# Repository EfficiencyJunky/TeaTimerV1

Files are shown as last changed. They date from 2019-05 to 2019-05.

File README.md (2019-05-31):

# TeaTimer

This is a simple yet elegant tea timer that will allow you to properly time your brews every time! You can build one yourself with the components listed in the BOM, and then upload the Arduino code in the "TeaTimer_Main_V1" folder to make it work. If you have access to a 3D printer, you can print an enclosure using the files in the "3DPrintFiles" folder  to make it easy to assemble and look more polished.

Of course this is all up for interpretation! Please take this project and modify it and make it everything you want it to be. The simplest modification would be simply to purchase a smaller, cheaper battery. You could easily knock $10 off the price, make it smaller, and it will work just as well.

For what it's worth though, I will provide documentation on how I built mine in case you want a good a good place to start.

# See it in action
For some background into why I made this, and a demo of it in action, check out my instagram post here:
[https://www.instagram.com/p/ByHbxj5pm57/](https://www.instagram.com/p/ByHbxj5pm57/)

# Build your own!
This project is a great way to get your feet wet in DIY product making. It requires only basic knowledge of Arduino, breadboarding, soldering, and optional 3D Printing.

### Acquire the Parts
The version I built cost around $60 in parts. All of the components can be purchased on Adafruit.com 

Here's the parts list (aka BOM or Bill of Materials) with links and descriptions of everything you'll need to create your very own Tea Timer V1
[BOM-aka-parts_list.csv](https://github.com/EfficiencyJunky/TeaTimerV1/blob/master/BOM-aka-parts_list.csv "BOM-aka-parts_list.csv")

Once you have the parts, you will need to do a little bit of Soldering to get them all prepped to plug and play.

The hardest soldering job will be soldering the Adafruit LiIon/LiPoly Backpack onto the Pro Trinket. They sort of describe how to do this on the product page, so hopefully it's not too hard to figure that out! Before you solder the Backpack to the Trinket Pro though, be sure to solder a dual header or pair of wires with at least 8 inches to the two holes on the LiIon/LiPoly Backpack that allow you to attach an on/off switch. Here's a picture that shows what I'm talking about
[https://cdn-shop.adafruit.com/970x728/2124-01.jpg](https://cdn-shop.adafruit.com/970x728/2124-01.jpg)
Of course the switch I have spec'd in the BOM is not the same switch in the picture, but the connections will be the same. In my build, I soldered a right angle dual header instead of bare wires and avoided soldering to the on/off switch by using one of these Arcade Button Quick-Connect Pairs (included in the BOM https://www.adafruit.com/product/1152)

Besides that, the only other soldering jobs will be connecting wires to terminals on the On/Off switch, 8 Position Rotary Switch, and Button with RGB LED.

Here's a picture that shows how I connected all the wires:
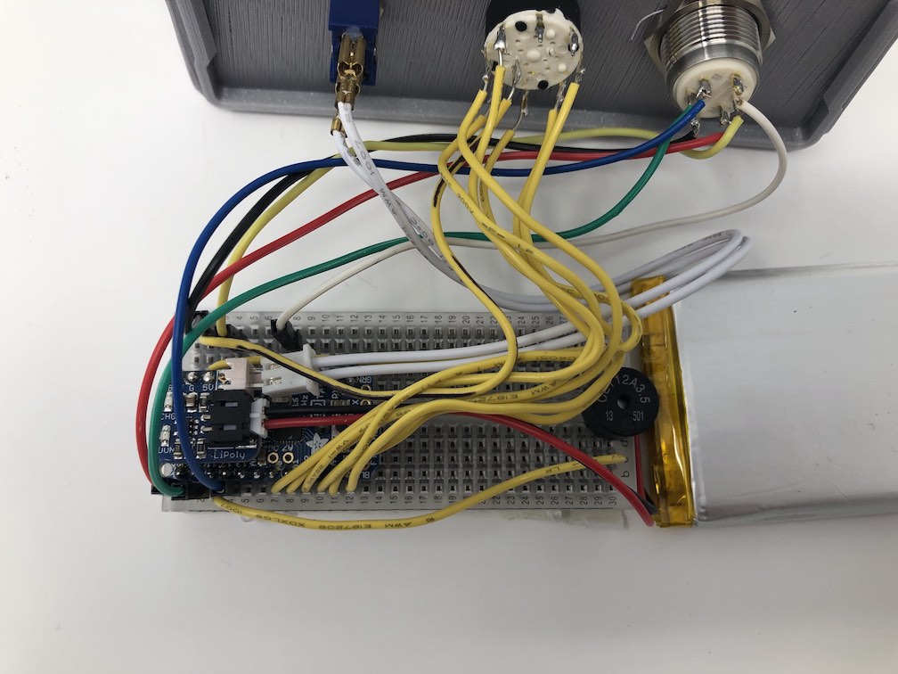
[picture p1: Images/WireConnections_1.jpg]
Wire Connections 1


I know it's probably not the easiest to follow, but it's all I got for now.

I'll be adding an entire schematic to make this all a lot easier as soon as I can.

For now, I need to go to sleep!
<!--stackedit_data:
eyJoaXN0b3J5IjpbLTEwMTE0MTc5NTIsMTAwMjQ2MzI3Myw4Mz
Q3OTA3ODcsMTIzMDY1MzY4MV19
-->

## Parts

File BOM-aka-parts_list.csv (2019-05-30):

Line Number | Manufacturer | Manufacturer P/N | Description | Vendor | Vendor P/N | Quantity | Price/Unit | Total Price | Link | Datasheet/CAD | Notes
01 | Adafruit |  | Pro Trinket - 5V 16MHz | Adafruit | 2000 | 1 | $9.95 | $9.95 | https://www.adafruit.com/product/2000
02 | Adafruit |  | Pro Trinket LiIon/LiPoly Backpack | Adafruit | 2124 | 1 | $4.95 | $4.95 | https://www.adafruit.com/product/2124
03 | Adafruit |  | Lithium Ion Polymer Battery - 3.7v 2500mAh | Adafruit | 328 | 1 | $14.95 | $14.95 | https://www.adafruit.com/product/328
04 | Adafruit |  | Mini Panel Mount SPDT Toggle Switch | Adafruit | 3221 | 1 | $0.95 | $0.95 | https://www.adafruit.com/product/3221
05 | Adafruit |  | Mini 8-Way Rotary Selector Switch - SP8T | Adafruit | 2925 | 1 | $1.95 | $1.95 | https://www.adafruit.com/product/2925
06 | Adafruit |  | Slim Metal Potentiometer Knob - 10mm Diameter x 10mm - T18 | Adafruit | 2058 | 1 | $0.95 | $0.95 | https://www.adafruit.com/product/2058
07 | Adafruit |  | Rugged Metal Pushbutton - 16mm 6V RGB Momentary | Adafruit | 3350 | 1 | $10.95 | $10.95 | https://www.adafruit.com/product/3350
08 | Adafruit |  | Buzzer 5V - Breadboard friendly | Adafruit | 1536 | 1 | $0.95 | $0.95 | https://www.adafruit.com/product/1536 | http://www.chinasound.com/Product/CET/CET12A3.5-42-2.0R.htm
09 | Adafruit |  | Half-size breadboard | Adafruit | 64 | 1 | $5.00 | $5.00 | https://www.adafruit.com/product/64
10 | Adafruit |  | Arcade/Button Quick-Connect Wire Pair - Set of 10 pairs | Adafruit | 1152 | 1 | $4.95 | $4.95 | https://www.adafruit.com/product/1152
11 | Adafruit |  | Solid-Core Wire Spool - 25ft - 22AWG - Yellow | Adafruit | 289 | 1 | $2.95 | $2.95 | https://www.adafruit.com/product/289
12 | Adafruit |  | Premium Male/Male Jumper Wires - 20 x 6" (150mm) | Adafruit | 1957 | 1 | $1.95 | $1.95 | https://www.adafruit.com/product/1957
13 | Local hardware store |  | m3 x 15mm (or 16mm) screw | Hardware store |  | 2 | $0.10 | $0.20
14 | Local hardware store |  | m3 hex nut | Hardware store |  | 2 | $0.10 | $0.20
 |  |  |  |  |  |  | TOTAL | $60.85

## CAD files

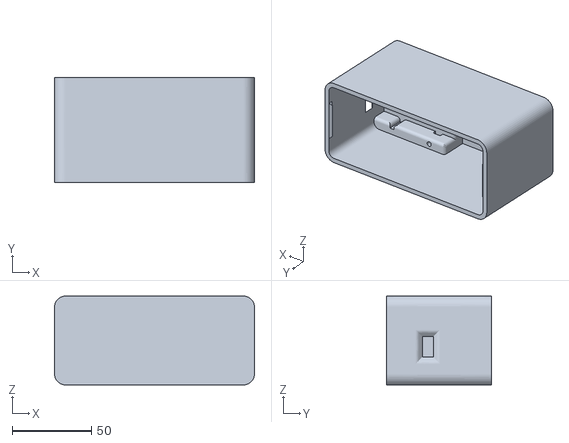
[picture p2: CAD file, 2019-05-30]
3DPrintFiles/Enclosure_Tea Timer Enclosure V1 v17_Case_v2.stl
126.0 x 66.0 x 56.0

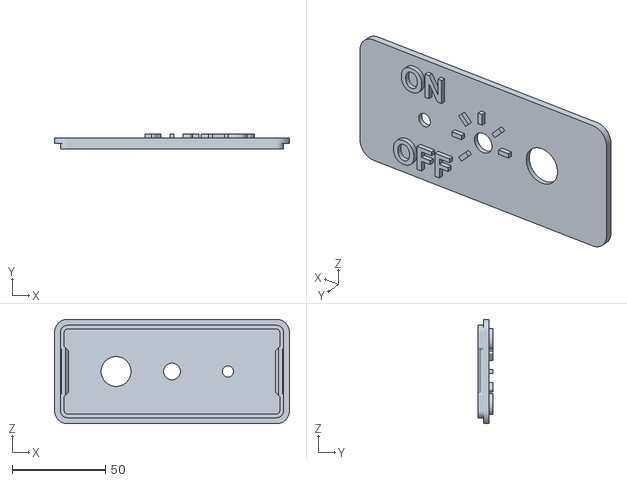
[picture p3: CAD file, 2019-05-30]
3DPrintFiles/Enclosure_Tea Timer Enclosure V1 v11_Top Cover_1_Top Cover_Top Cover.stl
126.0 x 8.00 x 56.0

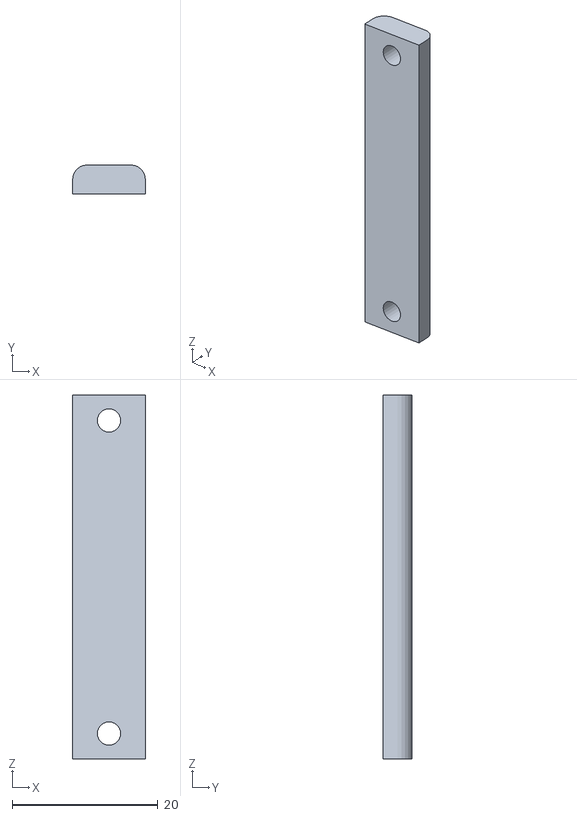
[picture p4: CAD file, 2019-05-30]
3DPrintFiles/Enclosure_Tea Timer Enclosure V1 v11_Case_1_Bridge to secure PCB.stl
10.0 x 4.00 x 50.0

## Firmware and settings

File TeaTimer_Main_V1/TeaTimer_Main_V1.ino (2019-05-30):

/*
  Welcome to the TeaTimer V1 - This is a simple yet elegant code base for creating a tea timer (or any kind of timer) 
                                that doesn't use the dreaded process blocking "delay()" function so that the user is free
                                to push that damn button anytime they please!

                                The timing and speed of everything is set up to work with the Adafruit Trinket Pro 5V
                                If you use a faster Arduino board, you may need to modify the variables
                                "ledFadeInterval" and "LEDFadeIndexStepIncrementAmount" in the MyStateMachine.cpp class

                                Ok enough chit chat, enjoy drinking your perfectly brewed tea!
*/


#include "MyStateMachine.cpp"

#define BUTTON_PIN 5
#define NUM_ROTARY_POSITIONS 6

// migrate this define and enum to the MyStateMachine class
//#define COMMON_ANODE

// Program State types supported:
//enum  states { NONE, COUNTING_DOWN, COUNTDOWN_COMPLETE};
 
int redPin = 9;
int greenPin = 10;
int bluePin = 12;

int buzzerPin = 11;

const int buttonPin = 4;     // the number of the pushbutton pin


int systemState = 0;

int rotaryKnobMinuteSelection = 0;
int rotaryKnobPinCount = 1;

static const uint8_t analog_pins[] = {A0,A1,A2,A3,A4,A5};

// no longer need this class. It was fun while it lasted, but the StateMachine is better
//MyButtonClass TheButton(buttonPin);

MyStateMachine StateMachine(redPin, greenPin, bluePin, buzzerPin);

void setup() {
  // put your setup code here, to run once:
  pinMode(redPin, OUTPUT);
  pinMode(greenPin, OUTPUT);
  pinMode(bluePin, OUTPUT);
  
  pinMode(buttonPin, INPUT_PULLUP);

  pinMode(A0, INPUT_PULLUP);
  pinMode(A1, INPUT_PULLUP);
  pinMode(A2, INPUT_PULLUP);
  pinMode(A3, INPUT_PULLUP);
  pinMode(A4, INPUT_PULLUP);
  pinMode(A5, INPUT_PULLUP);

  //Serial.begin();
  delay(10);
  StateMachine.setColor(0, 0, 255);  // Blue light is initial state
}


// States
// 1) Idle
// 2) Counting down
// 3) Countdown Complete


void loop() {
  // put your main code here, to run repeatedly:
  // TheButton.Update(millis());
  StateMachine.Update(millis());


  if (digitalRead(buttonPin) == LOW) // Button pressed
  {

    //Serial.println("KnobCount: ");
    
      // this sets everything in motion and makes it so that if a person presses the button more than once,
      // it will work no matter what state the StateMachine is in
      StateMachine.StartCountdown(GetNumMinutesForTimer()+1); // add 1 because the index starts at 0
      
  }


}

// a relatively efficient way to read all the pins and find the one that is low (aka the one that the rotary switch is set to)
// we'll use this to set the number of minutes to countdown
unsigned long GetNumMinutesForTimer(){

  unsigned long rotaryKnobPinCount = 0;
  
  while((digitalRead(analog_pins[rotaryKnobPinCount]) != LOW) && (rotaryKnobPinCount < NUM_ROTARY_POSITIONS)){
  
      rotaryKnobPinCount++;
  }

  return rotaryKnobPinCount;

}

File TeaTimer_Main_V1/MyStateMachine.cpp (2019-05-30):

/*
  MyStateMachine.cpp - This is a simple state machine to gracefully handle setting the three states of the tea timer system, as well as 
                          the proper audio/visual feedback in the form of an RGB LED and Piezzo Speaker.
  
                          The 3 states are:
                          1) Idle/None -- this is the state it is in when first turned on. LED == blue
                          2) Counting down -- this is the state it is in when the button is pressed and it is counting down. LED == green
                          3) Countdown Complete -- this is the state it is in after the countdown is complete
                                                    immediately after countdown is complete, the buzzer will beep 3 times at 1,200hz
                                                    and the LED will start slowly pulsing RED

                        The state machine will respond to button press input no matter which state it is in
                        If the countdown is already in progress and the button is pressed, it will re-set the time interval
                        If the countdown has completed once already and the button is pressed, it will re-start the countdown
                        
                        The timing and speed of everything is set up to work with the Adafruit Trinket Pro 5V
                        If you use a faster Arduino board, you may need to modify the variables
                        "ledFadeInterval" and "LEDFadeIndexStepIncrementAmount" in the MyStateMachine.cpp class

                        Ok enough chit chat, enjoy drinking your perfectly brewed tea!
*/


#include "Arduino.h"

// if the LEDs are common annode we need to flip the RGB values
#define COMMON_ANODE

// Program State types supported:
// 1) Idle/None
// 2) Counting down
// 3) Countdown Complete
enum  states { NONE, COUNTING_DOWN, COUNTDOWN_COMPLETE};

// Patern directions supported. used to pleasantly pulse the LED:
enum  fadeDirection { FORWARD, REVERSE };

class MyStateMachine
{
  public:
  
  int redPin;
  int greenPin;
  int bluePin;

  int buzzerPin; // the piezo is connected to analog pin designated by this variable
  int frequency = 1200; // sets the frequency in Hz that the buzzer will sound at. 1200 is pretty much perfect
                        // in the BOM for this project, I specified using a 2khz active piezo which supposedly only requires 3-5v
                        // in order to get it to make a 2kHz tone. But I swear when I hooked everything up, 
                        // the piezo was able to be controlled by the "tone" function which worked as you'd expect it to
                        // and produced a nice tone at 1,200 Hz  ¯\_(ツ)_/¯
                        // if you have issues with the Piezo you're using. sorry
  
  int numberOfBeeps = 3; // the number of times we want the buzzer to beep after countdown is complete
  int buzzerCounter;

  states ActiveState;
  fadeDirection Direction;     // direction to run the pattern

  // this variable sets how many milliseconds to add for each position of the rotary switch (which looks like tick marks from the outside)
  // one minute is 60,000 millis duh! set this to 30,000 if you want each tick to be 30 second increments
  // or come up with some logic in the StartCountdown function to decide the number of seconds each tick represents if you wanna get fancy pants
  const unsigned long tickTimeMultiple = 60000;
  
  unsigned long MillisToCount;
  unsigned long CountdownStartTime;
  
  unsigned long updateInterval;   // milliseconds between updates
  unsigned long lastUpdate; // last update of position

  unsigned long buzzerInterval;   // milliseconds between updates
  unsigned long buzzerOnInterval;   // milliseconds between updates
  unsigned long buzzerOffInterval;   // milliseconds between updates
  unsigned long buzzerToneBeginTime;



  unsigned long ledFadeUpdate;   // milliseconds between updates
  unsigned long ledFadeInterval;
  int LEDFadeIndex;
  int LEDFadeIndexStepIncrementAmount;
  int TotalLEDFadeSteps;
  

  
  //unsigned long lastUpdate; // last update of position
  
  
  //void (*OnComplete)();  // Callback on completion of pattern

  
  // Constructor - 
  // initializes the member variables and state
  MyStateMachine(int theRedPin, int theGreenPin, int theBluePin, int theBuzzerPin)
  {
    redPin = theRedPin;
    greenPin = theGreenPin;
    bluePin = theBluePin;

    ActiveState = NONE;
    buzzerPin = theBuzzerPin;

    buzzerOnInterval = 100;  // the number of milliseconds each beep will be "on" for
    buzzerOffInterval = 200; // the number of milliseconds each beep will be "off" for (or pause) between beeping
    
    // in order to simplify the logic of how the buzzer turns on and off (and not use the dreaded blocking "delay" function), this additional variable is used to set the 
    // interval that the buzzer is "on" or "off" and is toggled by being set to either "buzzerOnInterval" or "buzzerOffInterval"
    // since the first time the buzzer will sound, it needs to be on, then that means we want it to be set to the "buzzerOnInterval" first
    buzzerInterval = buzzerOnInterval;
    buzzerCounter = 0; // the number of times the buzzer has turned on so far    
    buzzerToneBeginTime = 0; // used for the timer logic to know if it's been long enough since the last buzz

    Direction = FORWARD;
    ledFadeUpdate = 0;   // milliseconds between updates
    ledFadeInterval = 10; // effectively sets the speed at which the LED pulses. 10ms seems to be about right for the Trinket Pro's slow ass processor
    LEDFadeIndex = 0; // see the LEDUpdate function to understand this
    LEDFadeIndexStepIncrementAmount = 5; // a silly way to say "the amount of brightness to add to the LED everytime it updates"
    TotalLEDFadeSteps = 255; // essentially sets the max brightness that the LED can achieve
  }

  void Update(unsigned long currentTime)
  {
      if((millis() - lastUpdate) > updateInterval) // time to update
      {
          lastUpdate = millis();

          //Meat and potatoes
          // our state machine! Isn't it beautiful?
          switch(ActiveState)
          {
              case COUNTING_DOWN:
                  if((millis() - CountdownStartTime) > MillisToCount){// time to update
                    ActiveState = COUNTDOWN_COMPLETE;
                    buzzerToneBeginTime = millis();
                    buzzerCounter = 0;
                    //setColor(255, 0, 0);  // red
                  }

                  break;
              case COUNTDOWN_COMPLETE:
                  //TheaterChaseUpdate();
                  if(buzzerCounter < numberOfBeeps*2){
                    BuzzerUpdate();  
                  }
                  
                  LEDUpdate();
                                    
                  break;
              default:
                  break;
          }
      }
  }
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

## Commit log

2019-05-30 Add the Arduino code files
2019-05-30 add 3d print files and BOM
    [BOM-aka-parts_list.csv, BOM-aka-parts_list.xlsx, Enclosure_Tea Timer Enclosure V1 v11_Case_1_Bridge to secure PCB.stl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]
2019-05-31 add image of wire connections
